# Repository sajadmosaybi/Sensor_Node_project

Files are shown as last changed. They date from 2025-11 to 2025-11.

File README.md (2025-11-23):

# Sensor_Node_project
Sensor_Node_Project is a low-power embedded system that uses the STM32L072 microcontroller to collect temperature and humidity data from the SHT31 sensor and transmit it via the RFM95 LoRa module. It provides a modular, scalable solution for IoT applications such as smart agriculture, vertical farming, and remote environmental monitoring.

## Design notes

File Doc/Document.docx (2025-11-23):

1. مقدمه

با توجه به رشد جمعیت و محدودیت منابع کشاورزی، استفاده از روش‌های نوین کشاورزی به ویژه کشاورزی عمودی [^1]به عنوان راهکاری پایدار و کارآمد برای تولید محصولات تازه و با کیفیت در فضاهای محدود، اهمیت فزاینده‌ای یافته است. سیستم‌های کشاورزی عمودی قادرند شرایط محیطی شامل دما، رطوبت، نور و تغذیه گیاه را به‌طور دقیق کنترل کرده و بازدهی تولید محصولات را افزایش دهند. در این پروژه، یک سیستم هوشمند کشاورزی عمودی مبتنی بر اینترنت اشیا [^2]طراحی و پیاده‌سازی شده است که شامل اجزای مختلفی است. هر واحد سنسور [^3]مجهز به میکروکنترلر STM32L4 و ماژول ارتباطی LoRa برای جمع‌آوری داده‌های محیطی و انتقال بی‌سیم آن‌ها به Gateway است. Gateway مبتنی بر STM32MP157 است که داده‌های دریافتی از نودها را جمع‌آوری کرده و به سرور محلی ارسال می‌کند. بخش سرور و Backend با استفاده از پلتفرم .NET Core و زبان برنامه‌نویسی Visual Basic توسعه یافته و مسئول دریافت، پردازش و مدیریت داده‌ها است و امکان ذخیره‌سازی اطلاعات در پایگاه داده‌های SQL Server یا SQLite و ارائه API برای ارتباط با Frontend را فراهم می‌کند. بخش Frontend نیز با استفاده از Visual Basic .NET Core و Windows Forms یا WPF طراحی شده و داشبوردی گرافیکی برای نمایش وضعیت محیط به‌صورت Real-Time ارائه می‌دهد که شامل نمودارهای دما، رطوبت و نور و قابلیت تنظیم هشدارها و کنترل دستی تجهیزات است. این طراحی ضمن کاهش مصرف انرژی نودها، انتقال پایدار داده‌ها و مدیریت متمرکز اطلاعات را فراهم می‌کند و رابط کاربری ساده و قابل توسعه‌ای را برای کاربر ایجاد می‌نماید. ساختار کلی و نحوه ارتباط اجزا در این سیستم در شکل ۱ نشان داده شده است .در مجموع، این سیستم نمونه‌ای عملی از ترکیب فناوری‌های IoT، میکروکنترلر و توسعه نرم‌افزار مبتنی بر .NET Core و Visual Basic برای تحقق کشاورزی مدرن و هوشمند محسوب می‌شود.

با توجه به ساختار ارائه‌شده در شکل 1، این سیستم یک معماری کنترل متمرکز برای کشت عمودی را پیاده‌سازی می‌کند. سیستم مبتنی بر معماری Master-Slave است که در آن یک واحد اصلی (Master) متشکل از MPU و MCU، مسئولیت اجرای سرور وب، پایش بلادرنگ وضعیت سیستم، ثبت داده‌ها در پایگاه داده و مدیریت ارتباطات شبکه را بر عهده دارد. واحد اصلی از طریق پروتکل‌های ارتباطی بیسیم با گره‌های کنترلی (Node) و سنسورها در تعامل است.

گره‌های کنترلی وظیفه راه‌اندازی عملگرها شامل پمپ‌ها، شیرهای نور و رله‌ها را از طریق درایورهای GPIO و SPI تحت سیستم عامل بلادرنگ (RTOS) انجام می‌دهند. از سوی دیگر، سنسورهای محیطی شامل دما، رطوبت، EC، PH و CO2 داده‌های محیطی را جمع‌آوری و از طریق ماژول‌های رابط به واحد اصلی ارسال می‌کنند. یک واحد فرعی (Slave MCU) نیز به منظور پردازش بلادرنگ داده‌های سنسوری و تولید سیگنال‌های هشدار و تأیید در نظر گرفته شده است.

این چارچوب امکان مدیریت یکپارچه و نظارت مستمر بر پارامترهای حیاتی کشت عمودی را با قابلیت اطمینان بالا و پاسخگویی بلادرنگ فراهم می‌سازد.

با توجه به نیازمندی پروژه و ساختار تعریف شده در پروژه، فقط بخش Node طراحی و پیاده‌سازی شده است.

شکل 1 ساختار کلی سیستم هوشمند Vertical Farming و نحوه ارتباط بین Sensor Node، Gateway و سرور

2. معرفی و نقش Sensor Node

Sensor Node واحد حسگر و جمع‌آوری داده‌ها در سیستم Vertical Farming است. نقش اصلی این نود، پایش پارامترهای محیطی مانند دما، رطوبت، نور و رطوبت خاک و ارسال داده‌ها به Gateway به صورت بی‌سیم و پایدار است. هر نود به صورت مستقل عمل می‌کند، اما می‌تواند با سایر نودها و Gateway در شبکه LoRa هماهنگ شود تا یک شبکه گسترده و مقیاس‌پذیر ایجاد گردد.

3. اجزا و سخت‌افزار Sensor Node

الف) میکروکنترلر

- مدل پیشنهادیSTM32L072
- ویژگی‌ها: مصرف انرژی بسیار پایین، مناسب کار با باتری، هسته ARM Cortex-M4 با FPU، قابلیت پردازش سنسورهای دیجیتال و آنالوگ، دارای ADC داخلی برای سنجش سیگنال‌های آنالوگ سنسورها، پشتیبانی از پروتکل‌های ارتباطی SPI، I2C، UART برای اتصال به ماژول LoRa و سنسورها

ب) ماژول ارتباطی LoRa

- مدل پیشنهادیRFM95
- ویژگی‌ها: انتقال داده بی‌سیم با برد بلند (1 تا 10 کیلومتر در فضای باز)، مصرف انرژی پایین و مناسب برای باتری، قابلیت پیکربندی فرکانس و نرخ داده، اتصال به میکروکنترلر از طریق SPI

ج) سنسورها

1. دما و رطوبت هوا SHT31: خروجی دیجیتال، دقت بالا، اتصال I2C یا تک سیم
2. نور محیط: BH1750 خروجی دیجیتال I2C، سنجش Lux
3. رطوبت خاک: Capacitive Soil Moisture Sensor خروجی آنالوگ، مقاوم در برابر خوردگی، اتصال به ADC میکروکنترلر
4. اختیاری – pH و EC آب: سنسورهای آنالوگ مخصوص کشاورزی هیدروپونیک

منبع تغذیه: باتری لیتیوم یونی یا لیتیوم پلیمر یا پک باتری چند سلولیو ماژول رگولاتورPower Management برای تأمین ولتاژ ثابت 3.3 یا 5 ولت برای سنسورها و ماژول LoRa

هـ) برد و اتصالات: PCB با مسیرهای کوتاه برای کاهش نویز، کانکتورهای I2C و SPI برای سنسورها و LoRa، هدرهای استاندارد برای اتصال راحت سنسورها

4. ساختار داخلی و نحوه ارتباط اجزا

Sensor Node از چند بخش اصلی تشکیل شده است:

- واحد پردازش مرکزی: STM32L072 به عنوان مغز نود، داده‌ها را از سنسورها می‌خواند، پردازش می‌کند و آماده ارسال می‌کند.
- واحد حسگر: شامل سنسورهای دیجیتال و آنالوگ که مقادیر محیطی را اندازه‌گیری می‌کنند و داده‌ها را به میکروکنترلر ارسال می‌کنند.
- واحد ارتباطی: ماژول LoRa که داده‌ها را به صورت بسته‌های کوتاه به Gateway ارسال می‌کند.
- واحد تغذیه: باتری و رگولاتور که انرژی لازم برای کل مدار را تأمین می‌کنند.

نحوه ارتباط داخلی:

- سنسورهای دیجیتال (I2C) → خطوط SDA و SCL به STM32L072
- سنسورهای آنالوگ → کانال‌های ADC داخلی → STM32L072
- STM32L4 → SPI → ماژول LoRa → ارسال بی‌سیم به Gateway
- تغذیه همه اجزا از رگولاتور 3.3 یا 5 ولت
5. پروتکل ارتباطی و انتقال داده
- LoRa P2P: در شبکه LoRa، هر Sensor Node بسته‌های داده‌ای خود را با فرمت مشخص به Gateway ارسال می‌کند. هر بسته شامل شناسه نود، زمان، نوع سنسور، مقدار اندازه‌گیری شده و CRC برای اطمینان از صحت داده است.

ارسال دوره‌ای یا بر اساس رویداد: نود می‌تواند داده‌ها را هر چند دقیقه یک‌بار ارسال کند یا وقتی مقدار سنسور از حد مشخصی عبور کرد.

6. نکات عملی پیاده‌سازی
- مصرف انرژی: استفاده از حالت Sleep میکروکنترلر بین ارسال داده‌ها، کاهش مصرف باتری تا چند هفته یا ماه
- دقت سنسورها: کالیبراسیون اولیه برای دما، رطوبت و رطوبت خاک
- نویز و اختلال: مسیرهای کوتاه PCB و فیلترهای خازنی برای کاهش نویز
- قابلیت توسعه: امکان افزودن سنسورهای دیگر مانند CO₂ یا شدت نور رشد گیاه
- امنیت داده‌ها: استفاده از CRC یا رمزگذاری ساده روی داده‌های LoRa برای جلوگیری از خطا یا دستکاری
7. پیشنهادات پروژه

با توجه به تحلیل انجام‌شده در طراحی و پیاده‌سازی سیستم هوشمند Vertical Farming، مجموعه‌ای از پیشنهادات برای بهبود عملکرد، پایداری و قابلیت توسعه سیستم ارائه شده است. این پیشنهادات شامل انتخاب سخت‌افزار، فناوری‌های ارتباطی، طراحی نرم‌افزار و مدیریت انرژی می‌باشند و هر یک بر اساس دلیل فنی و مزایای عملی خود انتخاب شده‌اند. جدول 1 پیشنهادات کلیدی پروژه را همراه با دلیل ارائه و مزایای آن‌ها نشان می‌دهد و می‌تواند راهنمایی برای توسعه و بهینه‌سازی سیستم در مراحل بعدی باشد.

جدول 1 پیشنهادات کلیدی برای بهبود عملکرد و پایداری سیستم Vertical Farming

مزیت | دلیل | پیشنهاد | شماره
افزایش عمر باتری نود و قابلیت پردازش لحظه‌ای داده‌ها | مصرف انرژی پایین و پردازش سریع برای داده‌های سنسور | استفاده از میکروکنترلر STM32L4 در Sensor Node | 1
انتقال پایدار داده‌ها بدون نیاز به اینترنت یا شبکه Wi-Fi | برد بلند و مصرف انرژی کم | بهره‌گیری از ماژول LoRa برای ارتباط بی‌سیم | 2
جمع‌آوری داده از تمام نودها و ارسال به سرور به صورت متمرکز | توان پردازشی کافی و اتصال آسان به شبکه محلی | استفاده از Raspberry Pi به عنوان Gateway | 3
مدیریت و پردازش داده‌ها، ایجاد API برای Frontend | سرعت بالا در پردازش و انعطاف در توسعه | پیاده‌سازی سرور و Backend با .NET Core و Visual Basic | 4
امکان تحلیل داده‌ها و ذخیره‌سازی طولانی مدت | ذخیره‌سازی پایدار و مدیریت داده‌های زمان‌محور | استفاده از پایگاه داده SQL Server یا SQLite | 5
مشاهده و مدیریت آسان وضعیت محیط و کنترل تجهیزات | ایجاد داشبورد گرافیکی و کنترل Real-Time | توسعه Frontend با Visual Basic .NET Core و WPF | 6
افزایش عمر باتری و کاهش هزینه نگهداری | کاهش مصرف انرژی در فواصل بین ارسال داده‌ها | استفاده از حالت Sleep و مدیریت انرژی در Sensor Node | 7
بهینه‌سازی رشد گیاه و افزایش بازدهی محصولات | پایش دقیق‌تر شرایط رشد گیاه | افزودن سنسورهای اضافی مانند pH، EC یا CO₂ | 8
کاهش نیاز به تعویض باتری و افزایش پایداری سیستم | شارژ خودکار نودها | امکان استفاده از پنل خورشیدی کوچک | 9
واکنش به موقع و جلوگیری از آسیب به گیاهان | اطلاع سریع از تغییرات محیطی یا خطاها | پیاده‌سازی هشدار و اعلان‌ها در Frontend | 10

8. طراحی ماژول اندازه‌گیری دما و رطوبت بر پایه STM32L072

در این بخش، وظیفه اصلی زیرسیستم اندازه‌گیری دما و رطوبت بر روی میکروکنترلر STM32L072، دریافت داده‌های محیطی از یک سنسور دقیق و کم‌مصرف و انتقال آن به لایه‌های بالاتر سیستم است. سنسور پیشنهادی برای این پروژه SHT31 از خانواده SENSIRION می‌باشد که یکی از معتبرترین و پایدارترین حسگرهای اندازه‌گیری دما و رطوبت در کاربردهای صنعتی و کشاورزی کنترل‌شده است. این حسگر از رابط ارتباطی I2C استفاده می‌کند و قادر است با دقت بالا داده‌های محیطی را در بازه‌های زمانی دوره‌ای ارسال کند. STM32L072 با وجود پشتیبانی سخت‌افزاری مناسب از پروتکل I2C، امکان راه‌اندازی این سنسور را با کمترین مصرف انرژی و بالاترین پایداری فراهم می‌سازد.

برای دستیابی به ساختاری پایدار، قابل نگهداری و توسعه‌پذیر، پیاده‌سازی لایه حسگر تنها به یک درایور خاص محدود نمی‌شود، بلکه این پروژه از یک لایه انتزاعی (Abstraction Layer) برای حسگرهای اندازه‌گیری دما و رطوبت استفاده می‌کند. در این لایه، کلاس یا ماژول مستقلی تعریف می‌شود که فقط وظایف سطح بالا مانند خواندن دما، خواندن رطوبت، مقداردهی اولیه و بررسی سلامت حسگر را ارائه می‌دهد، بدون آنکه به مدل خاصی وابسته باشد. به این ترتیب، پیاده‌سازی درایور واقعی هر حسگر مانند SHT31، SHT21، HTU21D یا DHT22 در لایه پایین‌تر قرار می‌گیرد و تنها از طریق این رابط انتزاعی با سیستم تعامل می‌کند. در نتیجه، در صورت نیاز به ارتقا یا تغییر حسگر در آینده، تنها بخش درایور اختصاصی آن اصلاح می‌شود و هیچ تغییری در لایه‌های بالاتر همچون ارتباط رادیویی، بخش پردازش داده یا مدیریت انرژی لازم نخواهد بود. این معماری باعث افزایش انعطاف‌پذیری سیستم، کاهش هزینه نگهداری و امکان سازگاری با نسل‌های جدید سنسورها می‌گردد.

[^1] Vertical Farming
[^2] IoT
[^3] Sensor Node

- تمامی مستندات و پیوست‌های پروژه در دایرکتوری پروژه قابل مشاهده است

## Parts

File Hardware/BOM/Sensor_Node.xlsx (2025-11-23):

Comment | Description | Designator | Footprint | LibRef | Quantity
7pF | CAP CER 7PF 50V NP0 0402 | C1, C2 | SMD-0402C | GJM1555C1H7R0DB01D | 2
100nF | CAP CER 0.1UF 10V X5R 0201 | C3, C4, C5, C7 | Cap0201 | GRM033R61A104ME15D | 4
1µF | CAP CER 1UF 10V X5R 0201 | C6 | Cap0201 | GRM033R61A105ME15D | 1
10µF | CAP CER 10UF 10V X7R 0805 | C8, C9 | SMD-0805C | GRJ21BR71A106KE01L | 2
4.7µF | CAP CER 4.7UF 6.3V X5R 0805 | C10 | SMD-0805C | GRM21BR60J475KA11L | 1
ANTENNA-SMA-90 | Connector SMA for Antenna, 90º. | j4 | ANTENNA-SMA-90 | ANTENNA-SMA-90 | 1
2.54 mm_THT_Vertical_20 pin | Pin Header WR-PHD, pitch 2.54 mm, THT, Vertical, dual row, 20 pin | J1 | 61302021121 | 61302021121 | 1
JST-2.54-2P-90 | Female Connector JST 2 Vias, 2.54mm 90º. | J3 | JST-2.54-2P-90 | JST-2.54-2P-90 | 1
3.3uH/1.4A | Inductor_3.3uH 20%_1.3A_SMD 25*20 | L1 | INDP2520x12N | ASPI-2515-3R3M-T2 | 1
62000411722 | WR-WTB THT Male Horizontal Shrouded Header, pitch 2mm, 4p | P1, P2 | 62000411722 | 62000411722 | 2
10k | RES SMD 10K OHM 1% 1/20W 0201 | R1, R2, R3, R4, R5, R6, R7, R8 | Res0201 | ERJ-1GEF1002C | 8
0R | RES_0 Ohm_ Jumper_1/16W_SMD 0402 | SB5 | Res0201 | RC0201JR-070RL | 1
TPSMD_25mil |  | TP1, TP2 | TPSMD_25mil | TPSMD_25mil | 2
STM32L072KBU6 | No Description Available | U1 | UFQFPN32-5x5mm-L | STM32L072KBU6 | 1
RFM95W-915S2 | Description | U2 | IC16_RFM95W-915S2_RFS | RFM95W-915S2 | 1
RT8008-33GB |  | U3 | SOT23, 5 | RT8008-33GB | 1
ABS07-166-32.768KHZ-T | Description | XTAL1 | XTAL_ABS07-166-32.768KHZ-T_ABR | ABS07-166-32.768KHZ-T | 1

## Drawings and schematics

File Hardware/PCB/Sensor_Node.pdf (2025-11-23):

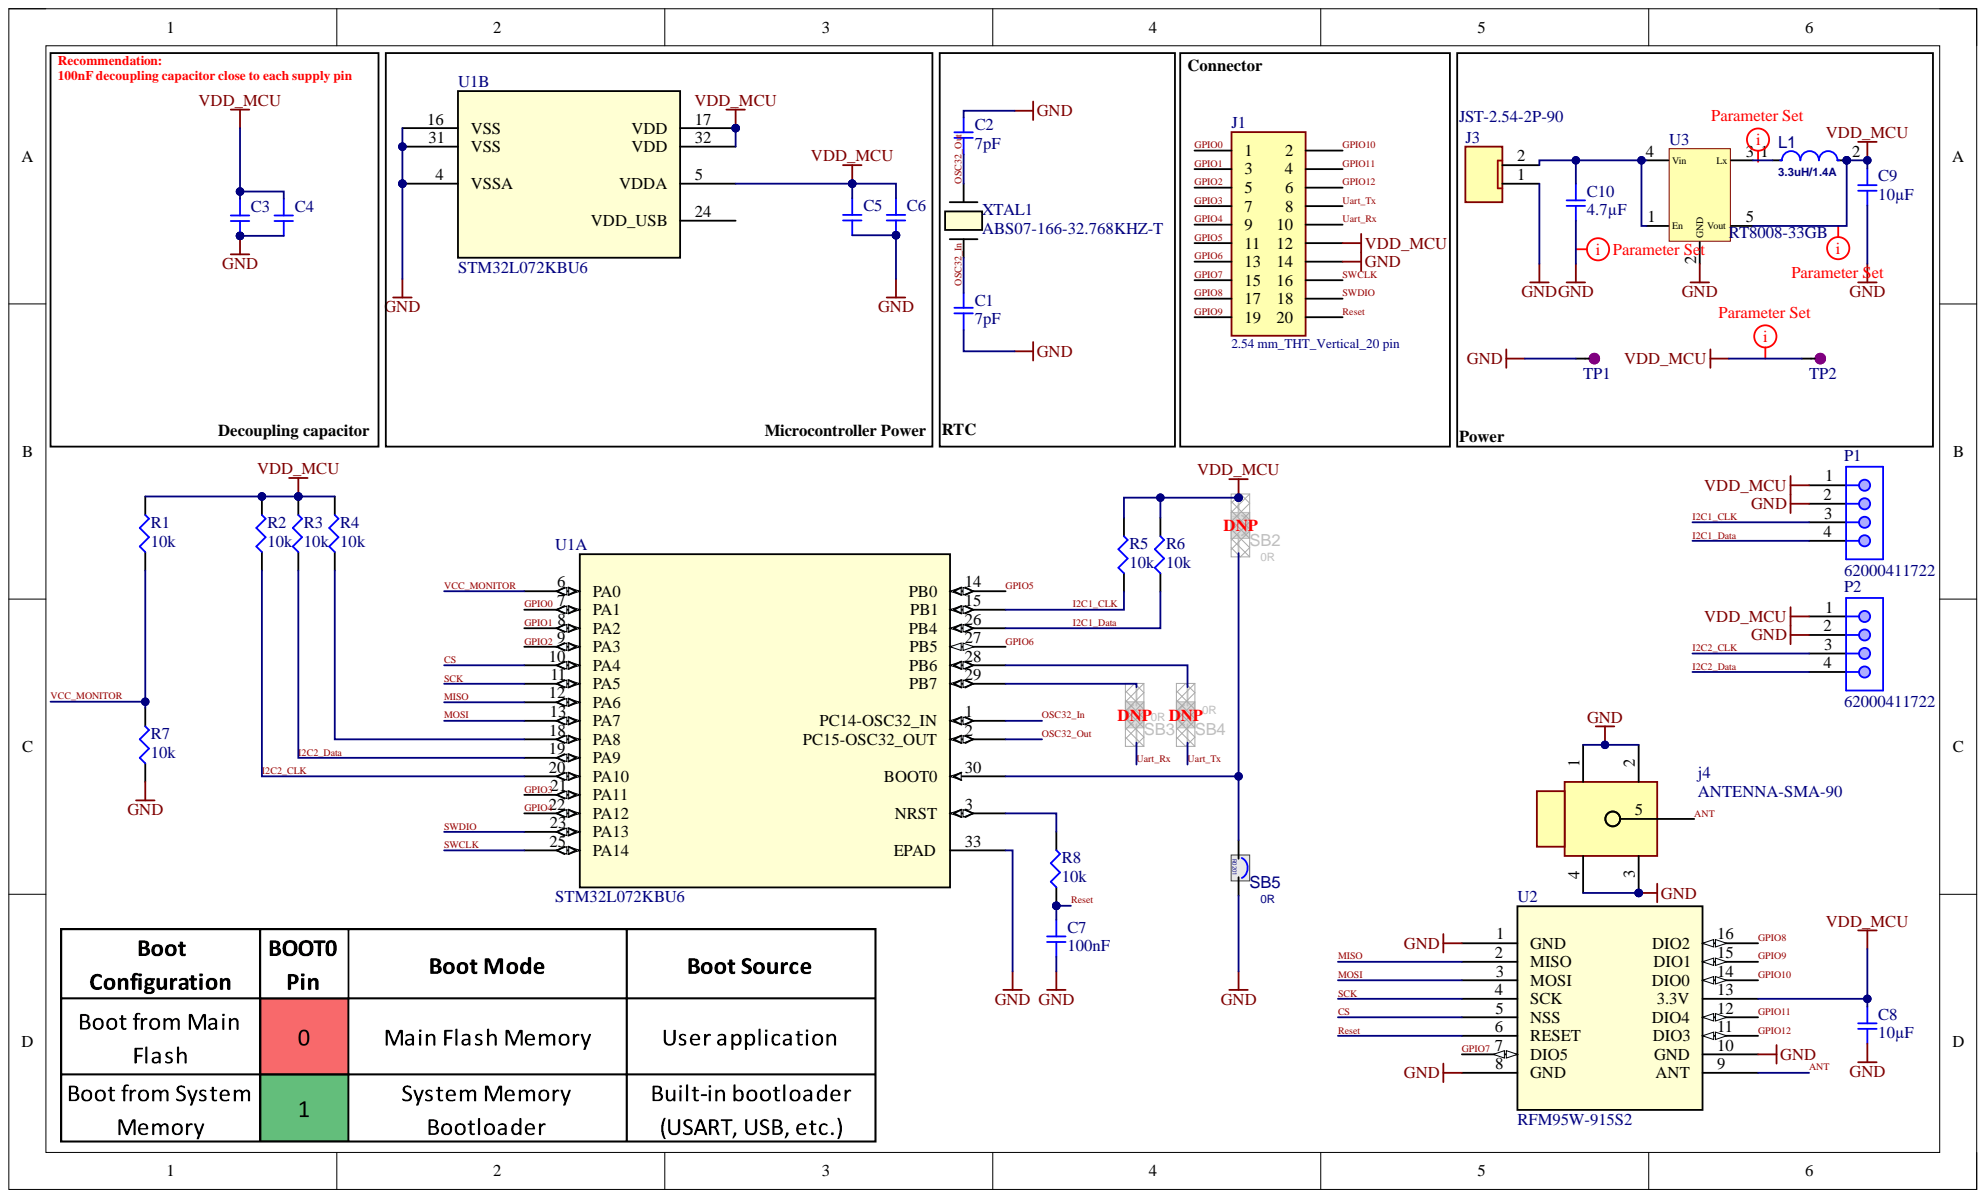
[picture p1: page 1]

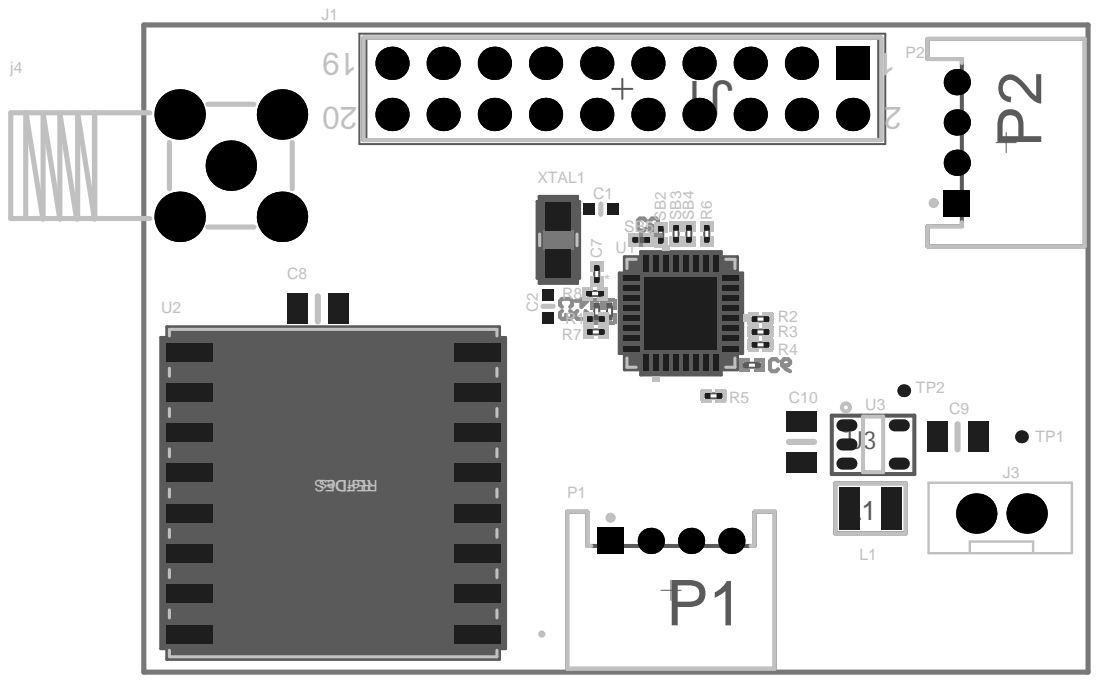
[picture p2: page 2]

Comment | Description | Designator | Footprint | LibRef | Quantity
7pF | CAPCER7PF50VNP0 0402 | C1, C2 | SMD-0402C | GJM1555C1H7R0DB01 D | 2
100nF | CAPCER0.1UF10V X5R0201 | C3, C4, C5, C7 | Cap0201 | GRM033R61A104ME15 D | 4
1µF | CAPCER1UF10VX5R 0201 | C6 | Cap0201 | GRM033R61A105ME15 D | 1
10µF | CAPCER10UF10V X7R0805 | C8, C9 | SMD-0805C | GRJ21BR71A106KE01L | 2
4.7µF | CAPCER4.7UF6.3V X5R0805 | C10 | SMD-0805C | GRM21BR60J475KA11 L | 1
ANTENNA-SMA-90 | Connector SMAfor Antenna, 90º. | j4 | ANTENNA-SMA-90 | ANTENNA-SMA-90 | 1
2.54 mm_THT_Vertical_20 pin | Pin Header WR-PHD, pitch 2.54mm, THT, Vertical, dual row, 20 pin | J1 | 61302021121 | 61302021121 | 1
JST-2.54-2P-90 | FemaleConnector JST 2Vias, 2.54mm 90º. | J3 | JST-2.54-2P-90 | JST-2.54-2P-90 | 1
3.3uH/1.4A | Inductor_3.3uH 20%_1.3A_SMD25*20 | L1 | INDP2520x12N | ASPI-2515-3R3M-T2 | 1
62000411722 | WR-WTBTHTMale Horizontal Shrouded Header, pitch 2mm, 4p | P1, P2 | 62000411722 | 62000411722 | 2
10k | RESSMD10KOHM1% 1/20W0201 | R1, R2, R3, R4, R5, R6, R7, R8 | Res0201 | ERJ-1GEF1002C | 8
0R | RES_0Ohm_ Jumper_1/16W_SMD 0402 | SB5 | Res0201 | RC0201JR-070RL | 1
TPSMD_25mil | | TP1, TP2 | TPSMD_25mil | TPSMD_25mil | 2
STM32L072KBU6 | No Description Available | U1 | UFQFPN32-5x5mm-L | STM32L072KBU6 | 1
RFM95W-915S2 | Description | U2 | IC16_RFM95W-915S2_RFS | RFM95W-915S2 | 1
RT8008-33GB | | U3 | SOT23, 5 | RT8008-33GB | 1
ABS07-166-32.768KHZ-T | Description | XTAL1 | XTAL_ABS07-166-32.768KHZ-T_ABR | ABS07-166-32.768KHZ-T | 1

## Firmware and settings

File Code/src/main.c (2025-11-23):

#include "sensor.h"
#include "sensor_sht31.h"
#include "rfm95.h"             // LoRa driver
#include <stdio.h>

extern I2C_HandleTypeDef hi2c1;
extern SPI_HandleTypeDef hspi1;
extern UART_HandleTypeDef huart2;

// LoRa handle
RFM95_Handle_t rfm;

// Timing intervals (ms)
#define SENSOR_READ_INTERVAL_MS 30000  // 30 sec
#define LORA_SEND_INTERVAL_MS   60000  // 1 min

int main(void) {
    HAL_Init();
    SystemClock_Config();
    MX_GPIO_Init();
    MX_I2C1_Init();
    MX_SPI1_Init();
    MX_USART2_UART_Init();

    // --- Select the sensor driver ---
    Sensor = SHT31_Driver;

    // --- Initialize sensor ---
    if (Sensor.Init(
        (Sensor.interface == SENSOR_IF_I2C) ? (void*)&hi2c1 :
        (Sensor.interface == SENSOR_IF_SPI) ? (void*)&hspi1 :
        (void*)&huart2
    ) != HAL_OK) {
        printf("Sensor init failed!\r\n");
    }

    // --- Initialize LoRa RFM95 ---
    rfm.hspi = &hspi1;
    rfm.cs_port = GPIOA;  // change if needed
    rfm.cs_pin = GPIO_PIN_4;
    RFM95_Init(&rfm);

    // Timing variables
    uint32_t last_read = HAL_GetTick();
    uint32_t last_send = HAL_GetTick();
    SensorData_t current_data = {0};

    while (1) {
        uint32_t now = HAL_GetTick();

        // --- Sensor Reading ---
        if ((now - last_read) >= SENSOR_READ_INTERVAL_MS) {
            Sensor.Trigger(
                (Sensor.interface == SENSOR_IF_I2C) ? (void*)&hi2c1 :
                (Sensor.interface == SENSOR_IF_SPI) ? (void*)&hspi1 :
                (void*)&huart2
            );
            HAL_Delay(15); // SHT31 measurement time
            current_data = Sensor.Read(
                (Sensor.interface == SENSOR_IF_I2C) ? (void*)&hi2c1 :
                (Sensor.interface == SENSOR_IF_SPI) ? (void*)&hspi1 :
                (void*)&huart2
            );
            last_read = now;

            if (current_data.error == 0)
                printf("Sensor Read -> T=%.2f C, RH=%.2f%%\r\n",
                        current_data.temperature_c,
                        current_data.humidity_rh);
            else
                printf("Sensor read error: %d\r\n", current_data.error);
        }

        // --- LoRa Transmission ---
        if ((now - last_send) >= LORA_SEND_INTERVAL_MS) {
            if (current_data.error == 0) {
                char buf[32];
                int len = sprintf(buf, "T=%.2fC,RH=%.2f%%",
                                  current_data.temperature_c,
                                  current_data.humidity_rh);
                RFM95_Send(&rfm, (uint8_t*)buf, len);
                printf("LoRa Sent: %s\r\n", buf);
            }
            last_send = now;
        }

        HAL_Delay(100); // small delay to reduce CPU usage
    }
}

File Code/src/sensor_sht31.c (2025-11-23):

#include "sensor.h"

#define SHT31_ADDR (0x44 << 1)
static const uint8_t CMD_SINGLE[2] = {0x24, 0x00};

static uint8_t crc8(const uint8_t *data, int len) {
    uint8_t crc = 0xFF;
    for (int j = 0; j < len; j++) {
        crc ^= data[j];
        for (int i = 0; i < 8; i++)
            crc = (crc & 0x80) ? (crc << 1) ^ 0x31 : (crc << 1);
    }
    return crc;
}

static HAL_StatusTypeDef SHT31_Init(void *handle) {
    I2C_HandleTypeDef *hi2c = (I2C_HandleTypeDef *)handle;
    uint8_t cmd[2] = {0x30, 0xA2}; // Soft reset
    return HAL_I2C_Master_Transmit(hi2c, SHT31_ADDR, cmd, 2, 100);
}

static HAL_StatusTypeDef SHT31_Trigger(void *handle) {
    I2C_HandleTypeDef *hi2c = (I2C_HandleTypeDef *)handle;
    return HAL_I2C_Master_Transmit(hi2c, SHT31_ADDR, (uint8_t*)CMD_SINGLE, 2, 100);
}

static SensorData_t SHT31_Read(void *handle) {
    SensorData_t r = {0};
    I2C_HandleTypeDef *hi2c = (I2C_HandleTypeDef *)handle;
    uint8_t buf[6];

    if (HAL_I2C_Master_Receive(hi2c, SHT31_ADDR, buf, 6, 100) != HAL_OK) {
        r.error = 1;
        return r;
    }
    if (crc8(buf, 2) != buf[2] || crc8(buf+3, 2) != buf[5]) {
        r.error = 2;
        return r;
    }

    uint16_t Traw = (buf[0]<<8)|buf[1];
    uint16_t Hraw = (buf[3]<<8)|buf[4];

    r.temperature_c = -45 + 175 * ((float)Traw / 65535.0f);
    r.humidity_rh = 100 * ((float)Hraw / 65535.0f);
    r.error = 0;
    return r;
}

// Export driver
SensorDriver_t SHT31_Driver = {
    .interface = SENSOR_IF_I2C,
    .Init = SHT31_Init,
    .Trigger = SHT31_Trigger,
    .Read = SHT31_Read
};

// Global pointer to active sensor
SensorDriver_t Sensor;
